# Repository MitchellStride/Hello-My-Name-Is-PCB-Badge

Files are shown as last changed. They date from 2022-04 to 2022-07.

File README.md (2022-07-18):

# The 'Hello my name is' PCB Badge
This **#Badgelife** PCB was created to test some circuits to be used in future art PCBs.
I also wanted a small project to bring to local hardware meetups. Partial assembly done at jlc.

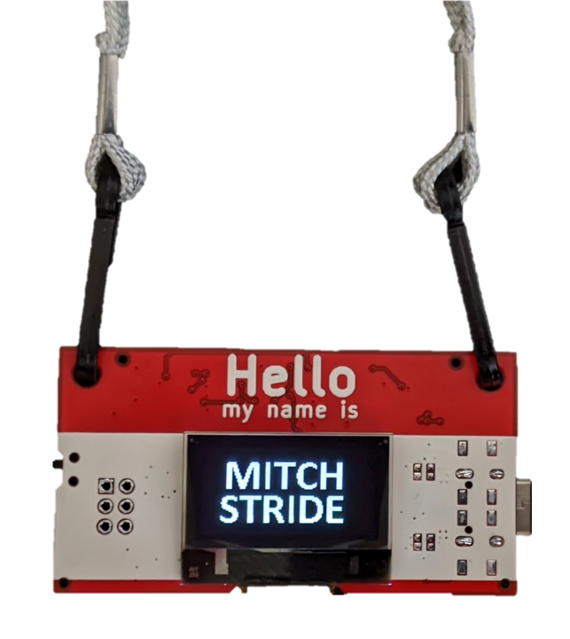
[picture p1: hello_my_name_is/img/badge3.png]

<br/>*missing front buttons on this test PCB
## Features:
* Powered by x2 AA Batteries
* Highly compatible with JLCPCB's basic SMT parts
* Raspberry Pi RP2040 uC w/ Dual core ARM Cortex-M0+
* OLED Screen, RGB LEDs, Buttons
* SAO Connector!

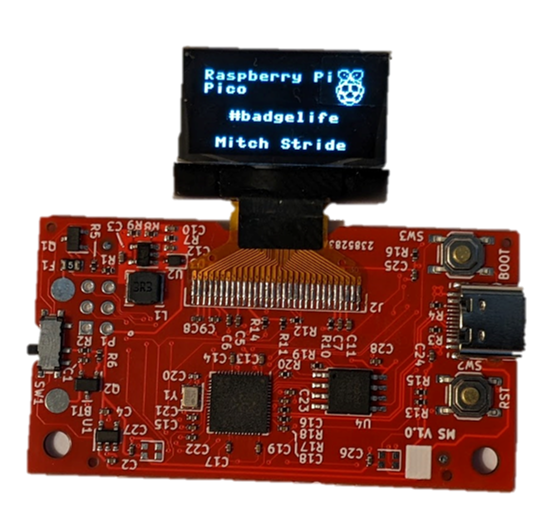
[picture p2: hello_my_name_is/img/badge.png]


## v1 Issues:
I rushed this project a lot. Schematic was done in a few nights, layout and routing in a few hours with no review. This PCB has a few mistakes. Not planning on making another board spin but leaving this list here. 
* I seen someone's design online using a RGB led running at 3.3V (below spec). I tried to replicate it and the LEDs were very flaky and worked intermittently. Experiment failed 😢.
* AA boost converter not yet tested, just using USB power so far.
### Possible v2 Wishlist [v2 Todo]:
* User led + pwr led 
* ON OFF silk on switch
* Buzzer would be fun
* 5.1k USB cc1 cc2
* Planes on batt terminals to prevent lifting
* Use RPI boost for AA supply instead of boost converter
		○ Its nice to have 5V for leds
* Sao is to big for this little thing.
* GND probe clip stuffing option
* lvl shifter for RGBs

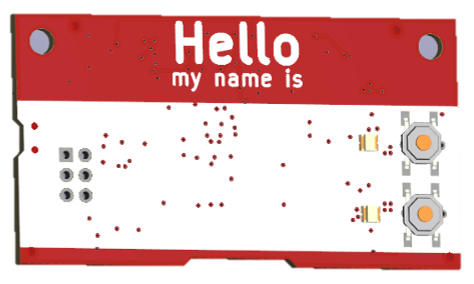
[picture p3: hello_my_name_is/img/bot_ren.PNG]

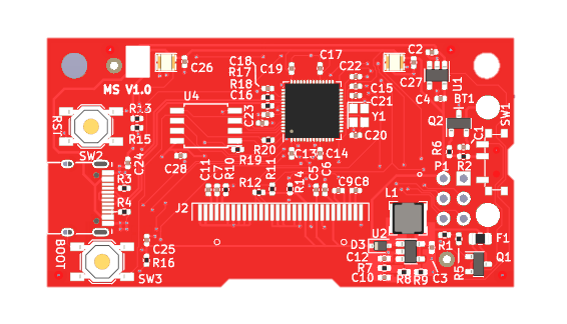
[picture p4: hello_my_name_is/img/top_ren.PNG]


## Example GIF ⚡


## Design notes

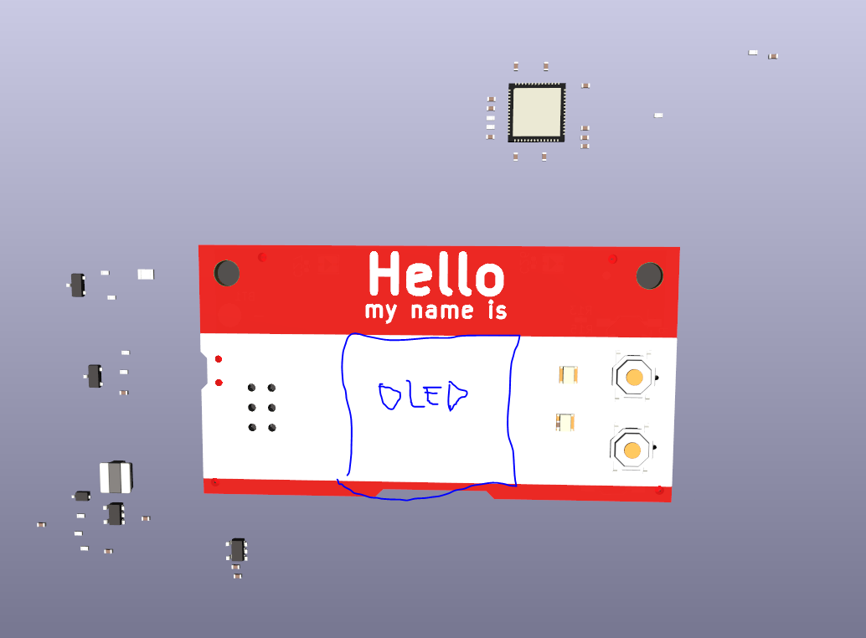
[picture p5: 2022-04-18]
hello_my_name_is/img/mockup.PNG

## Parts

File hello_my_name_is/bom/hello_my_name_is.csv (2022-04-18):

Reference | Quantity | Value | Footprint | Datasheet | digi | desc | lcsc | Field5
BT1 | 1 | AAx2 | ftp:BatteryHolder_MPD_BC2AAPC_2xAA_mod-SMD |  | BC2AAPC
C1 C5 C6 C8 C9 C12 C22 C23 C24 C25 C26 C27 C28 | 13 | 1u | Capacitor_SMD:C_0402_1005Metric |  |  | 25V X5R | C52923
C10 | 1 | 3.3p | Capacitor_SMD:C_0402_1005Metric |  |  |  | C1565
C13 C14 C15 C16 C17 C18 C19 | 7 | 0.1u | Capacitor_SMD:C_0402_1005Metric |  |  | 16V X7R | C1525
C2 C3 C4 C11 | 4 | 4.7u | Capacitor_SMD:C_0402_1005Metric |  |  | 10V X5R | C23733
C20 C21 | 2 | 12p | Capacitor_SMD:C_0402_1005Metric |  |  | 50V C0G | C1547
C7 | 1 | 2.2u | Capacitor_SMD:C_0402_1005Metric |  |  | 6.3V X5R | C12530
D1 D2 D4 D5 | 4 | WS2812B-2020 | ftp:WS2812B-2020 | https://www.tme.eu/Document/4a8239e52df5e0b5cc2eb96834c5d8b6/WS2812B-2020.pdf |  |  | C965555
D3 | 1 | 1N5819WS | Diode_SMD:D_SOD-323 |  |  | 40V 600mV@1A | C191023
F1 | 1 | 24V 500mA PTC | Fuse:Fuse_0805_2012Metric |  |  | NonAsm | C910822
J1 | 1 | USB_C_Receptacle_USB2.0 | ftp:USB-C-16p | https://www.usb.org/sites/default/files/documents/usb_type-c.zip |  |  | C167321
J2 | 1 | OLED | Display:OLED-128O064D |  |  | Shenzhen Allvision Tech N096-2864KSWEG01-H30 | C2890596
L1 | 1 | 3.3u | Inductor_SMD:L_Bourns-SRN4018 |  |  | ftp: Not Exact, 1.23A 3.3uH ±20% 70mΩ | C431259
P1 | 1 | SAO 2x3 IDC | ftp:Badgelife-SAOv169-BADGE-2x3 |  |  |  | C11214
Q1 | 1 | AO3401A | Package_TO_SOT_SMD:SOT-23 | http://www.aosmd.com/pdfs/datasheet/AO3401A.pdf |  |  | C15127
Q2 | 1 | AO3400A | Package_TO_SOT_SMD:SOT-23 | http://www.aosmd.com/pdfs/datasheet/AO3400A.pdf |  |  | C20917
R1 R2 R13 R14 R15 R16 R19 | 7 | 10k | Resistor_SMD:R_0402_1005Metric |  |  |  | C25744
R10 | 1 | 330k | Resistor_SMD:R_0402_1005Metric |  |  |  | C25778
R11 R12 | 2 | 4.7k | Resistor_SMD:R_0402_1005Metric |  |  |  | C25900
R17 R18 | 2 | 22 | Resistor_SMD:R_0402_1005Metric |  |  |  | C25092
R3 R4 | 2 | 56k | Resistor_SMD:R_0402_1005Metric |  |  |  | C25796
R5 R6 R20 | 3 | 1k | Resistor_SMD:R_0402_1005Metric |  |  |  | C11702
R7 | 1 | 200k | Resistor_SMD:R_0402_1005Metric |  |  |  | C25764
R8 | 1 | 51k | Resistor_SMD:R_0402_1005Metric |  |  |  | C25794
R9 | 1 | 150k | Resistor_SMD:R_0402_1005Metric |  |  |  | C25755
SW1 | 1 | SSSS811101 | ftp:SSSS811101 |  |  |  | C109335
SW2 SW3 SW4 SW5 | 4 | TS-1187A-B-A-B | Button_Switch_SMD:SW_SPST_TL3342 |  |  | ftp: Not Exact | C318884
U1 | 1 | RT9080-33GJ5 | Package_TO_SOT_SMD:SOT-23-5 | https://datasheet.lcsc.com/lcsc/2009192305_Richtek-Tech-RT9080-33GJ5_C841192.pdf |  | 3V3 600mA LDO | C841192
U2 | 1 | TPS61040DBV | Package_TO_SOT_SMD:SOT-23-5 | http://www.ti.com/lit/ds/symlink/tps61040.pdf |  |  | C7722
U3 | 1 | RP2040 | ftp:QFN-56_EP_7x7_Pitch0.4mm | https://datasheets.raspberrypi.org/rp2040/rp2040_datasheet.pdf |  |  | C2040
U4 | 1 | W25Q64JV | Package_SO:SOIC-8W_5.3x5.3mm_P1.27mm |  |  |  | C179171
Y1 | 1 | XYDBPCNANF-12MHZ | Crystal:Crystal_SMD_2520-4Pin_2.5x2.0mm |  |  |  | C521567

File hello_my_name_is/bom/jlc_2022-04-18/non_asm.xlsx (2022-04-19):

Reference | Value | Footprint | Quantity
BT1 | AAX2 | FTP:BATTERYHOLDER_MPD_BC2AAPC_2XAA_MOD-SMD | 1
J2 | OLED | DISPLAY:OLED-128O064D | 1
D1,D2,D4,D5 | WS2812B-2020 | FTP:WS2812B-2020 | 2
P1 | SAO 2X3 IDC | FTP:BADGELIFE-SAOV169-BADGE-2X3 | 0

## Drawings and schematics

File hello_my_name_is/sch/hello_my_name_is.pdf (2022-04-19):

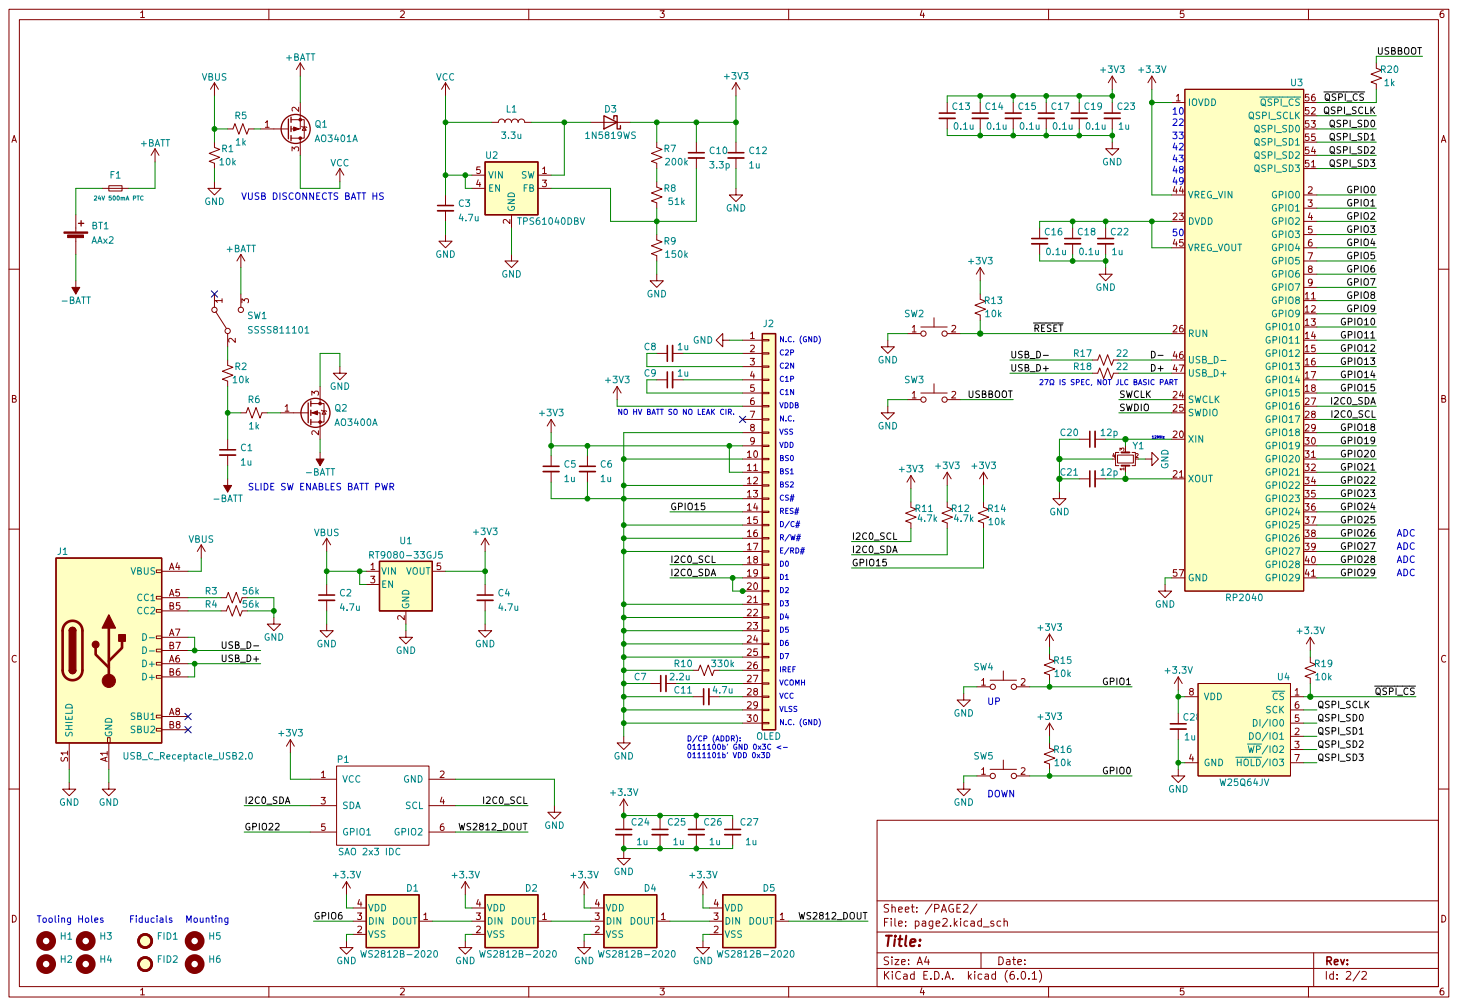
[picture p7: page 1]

þÿ27© IS SPEC, NOT JLC BASIC PART VUSB DISCONNECTS BATT HS

10
11

I2C0_SDA USB_D+ USB_D- SLIDE SW ENABLES BATT PWR
-BATT

D/CP (ADDR): 0111100b' GND 0x3C <- 0111101b' VDD 0x3D
1u GND GND

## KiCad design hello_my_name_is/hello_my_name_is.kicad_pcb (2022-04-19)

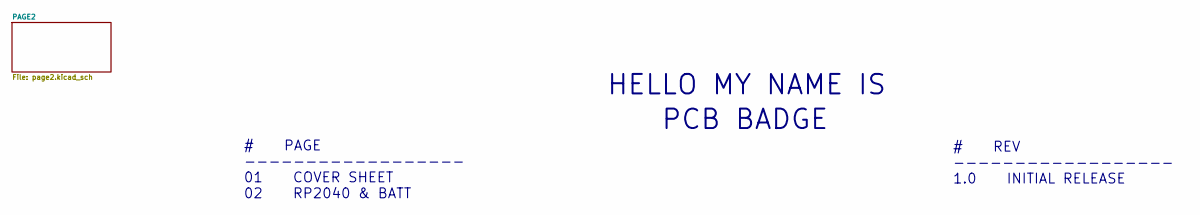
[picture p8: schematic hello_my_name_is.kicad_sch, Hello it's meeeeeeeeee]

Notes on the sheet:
# REV ------------------ 1.0 INITIAL RELEASE
HELLO MY NAME IS
PCB BADGE
# PAGE ------------------ 01 COVER SHEET 02 RP2040 & BATT

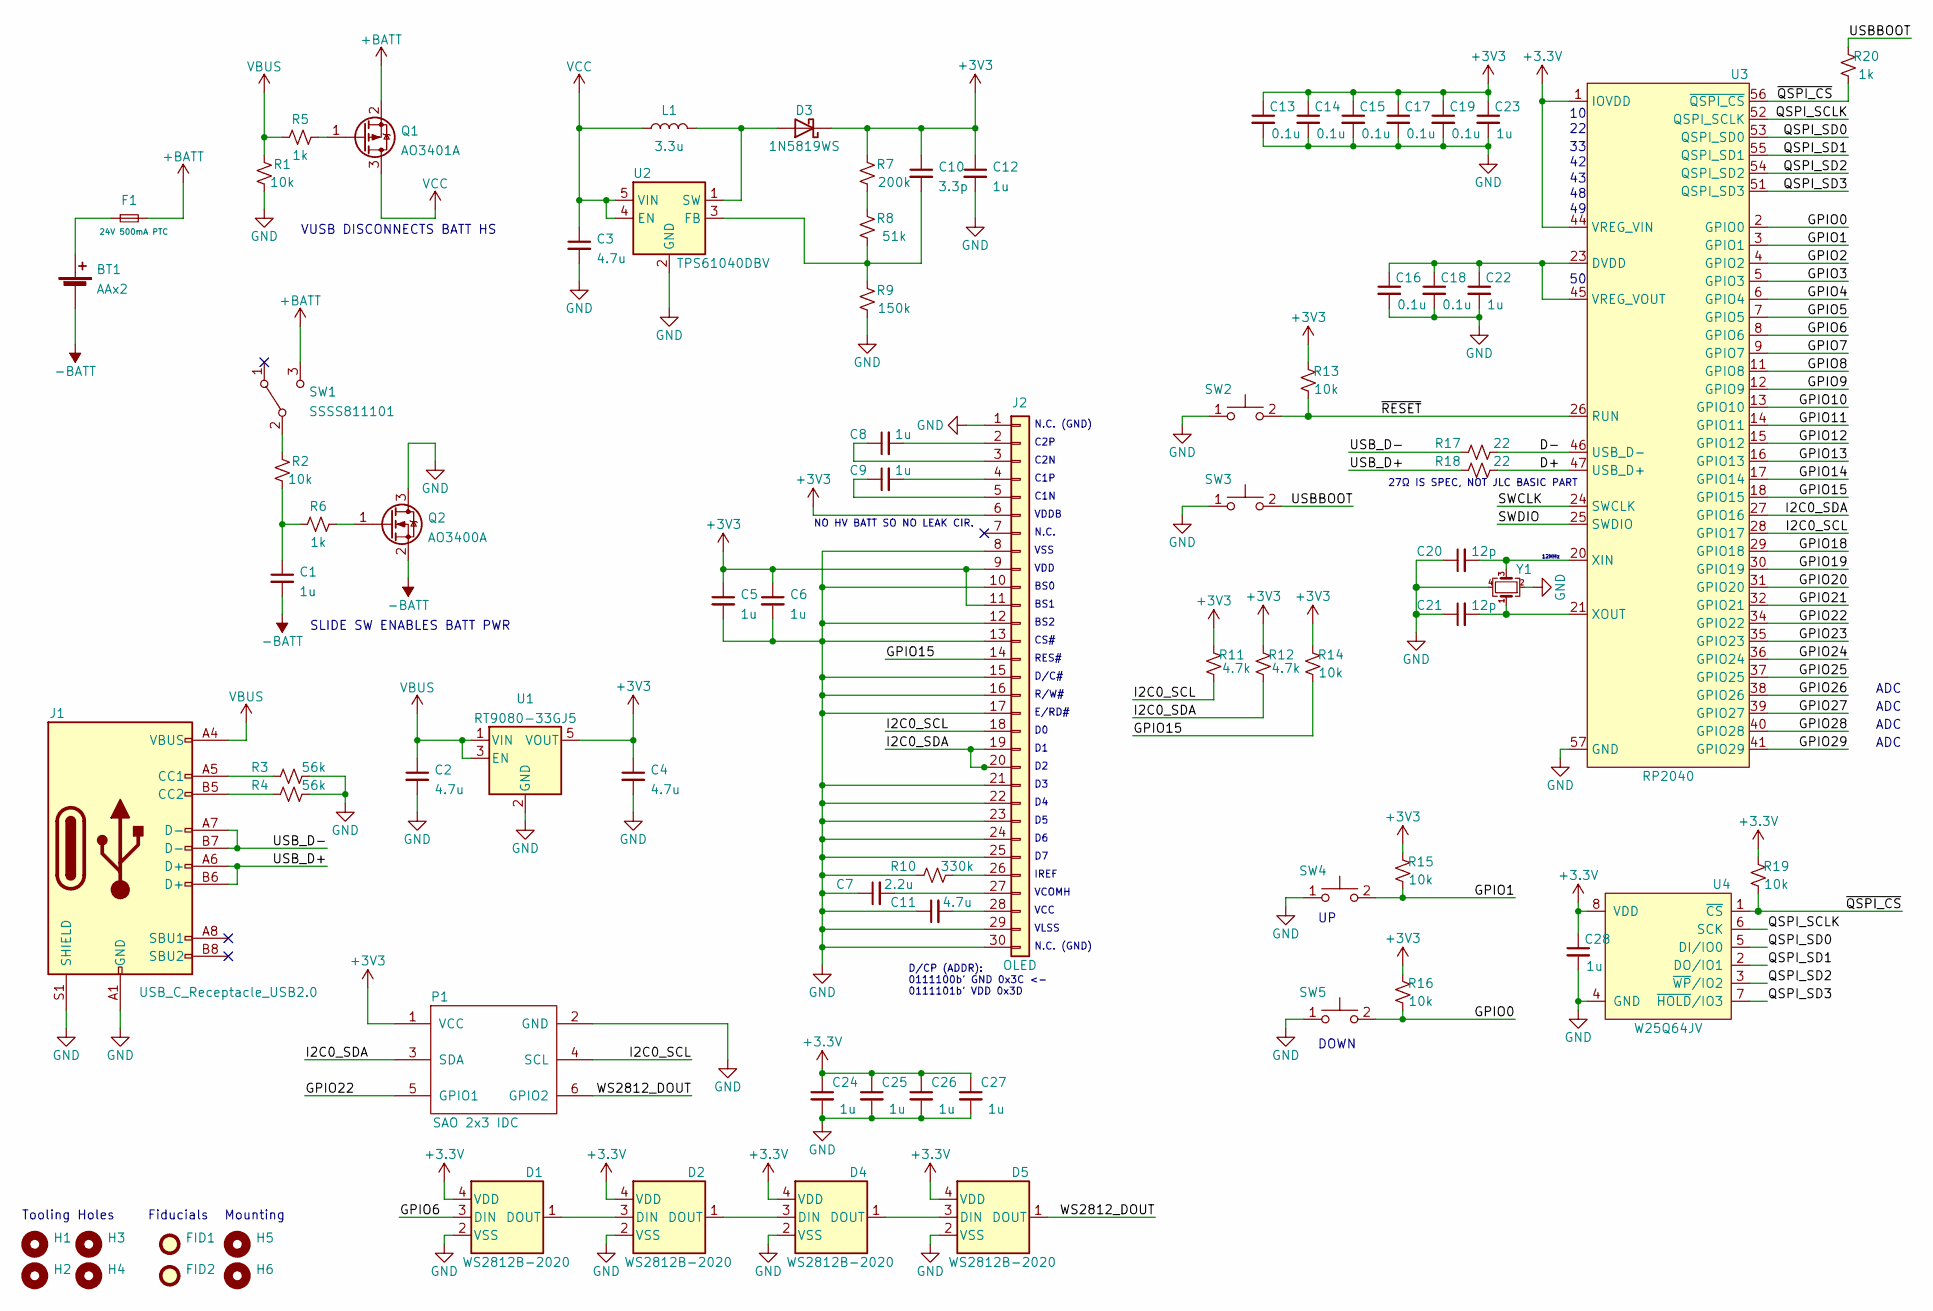
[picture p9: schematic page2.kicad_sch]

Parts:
BT1: AAx2; BatteryHolder_MPD_BC2AAPC_2xAA_mod-SMD; digi BC2AAPC
C1, C5, C6, C8, C9, C12, C22, C23, C24, C25, C26, C27, C28: 1u; C_0402_1005Metric; lcsc C52923
C2, C3, C4, C11: 4.7u; C_0402_1005Metric; lcsc C23733
C7: 2.2u; C_0402_1005Metric; lcsc C12530
C10: 3.3p; C_0402_1005Metric; lcsc C1565
C13, C14, C15, C16, C17, C18, C19: 0.1u; C_0402_1005Metric; lcsc C1525
C20, C21: 12p; C_0402_1005Metric; lcsc C1547
D1, D2, D4, D5: WS2812B-2020; lcsc C965555
D3: 1N5819WS; D_SOD-323; lcsc C191023
F1: 24V 500mA PTC; Fuse_0805_2012Metric; lcsc C910822
FID1, FID2: Fiducial; Fiducial_1mm_Mask2mm
H1, H2, H3, H4: Tooling_Hole_JLC; JLC_Tooling_Hole
H5, H6: Tooling_Hole_JLC; MountingHole_3.2mm_M3
J1: USB_C_Receptacle_USB2.0; USB-C-16p; lcsc C167321
J2: OLED; OLED-128O064D; lcsc C2890596
L1: 3.3u; L_Bourns-SRN4018; lcsc C431259
P1: SAO 2x3 IDC; Badgelife-SAOv169-BADGE-2x3; lcsc C11214
Q1: AO3401A; SOT-23; lcsc C15127
Q2: AO3400A; SOT-23; lcsc C20917
R1, R2, R13, R14, R15, R16, R19: 10k; R_0402_1005Metric; lcsc C25744
R3, R4: 56k; R_0402_1005Metric; lcsc C25796
R5, R6, R20: 1k; R_0402_1005Metric; lcsc C11702
R7: 200k; R_0402_1005Metric; lcsc C25764
R8: 51k; R_0402_1005Metric; lcsc C25794
R9: 150k; R_0402_1005Metric; lcsc C25755
R10: 330k; R_0402_1005Metric; lcsc C25778
R11, R12: 4.7k; R_0402_1005Metric; lcsc C25900
R17, R18: 22; R_0402_1005Metric; lcsc C25092
SW1: SSSS811101; lcsc C109335
SW2, SW3, SW4, SW5: TS-1187A-B-A-B; SW_SPST_TL3342; lcsc C318884
U1: RT9080-33GJ5; SOT-23-5; lcsc C841192
U2: TPS61040DBV; SOT-23-5; lcsc C7722
U3: RP2040; QFN-56_EP_7x7_Pitch0.4mm; lcsc C2040
U4: W25Q64JV; SOIC-8W_5.3x5.3mm_P1.27mm; lcsc C179171
Y1: XYDBPCNANF-12MHZ; Crystal_SMD_2520-4Pin_2.5x2.0mm; lcsc C521567

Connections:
+BATT: F1.2, Q1.2 (S), SW1.3 (C)
-BATT: BT1.2 (-), C1.2, Q2.2 (S)
/PAGE2/D+: R18.2, U3.47 (USB_D+)
/PAGE2/D-: R17.2, U3.46 (USB_D-)
/PAGE2/GPIO0: R16.2, SW5.2, U3.2 (GPIO0)
/PAGE2/GPIO1: R15.2, SW4.2, U3.3 (GPIO1)
/PAGE2/GPIO2: U3.4 (GPIO2)
/PAGE2/GPIO3: U3.5 (GPIO3)
/PAGE2/GPIO4: U3.6 (GPIO4)
/PAGE2/GPIO5: U3.7 (GPIO5)
/PAGE2/GPIO6: D1.3 (DIN), U3.8 (GPIO6)
/PAGE2/GPIO7: U3.9 (GPIO7)
/PAGE2/GPIO8: U3.11 (GPIO8)
/PAGE2/GPIO9: U3.12 (GPIO9)
/PAGE2/GPIO10: U3.13 (GPIO10)
/PAGE2/GPIO11: U3.14 (GPIO11)
/PAGE2/GPIO12: U3.15 (GPIO12)
/PAGE2/GPIO13: U3.16 (GPIO13)
/PAGE2/GPIO14: U3.17 (GPIO14)
/PAGE2/GPIO15: J2.14, R14.2, U3.18 (GPIO15)
/PAGE2/GPIO18: U3.29 (GPIO18)
/PAGE2/GPIO19: U3.30 (GPIO19)
/PAGE2/GPIO20: U3.31 (GPIO20)
/PAGE2/GPIO21: U3.32 (GPIO21)
/PAGE2/GPIO22: P1.5 (GPIO1), U3.34 (GPIO22)
/PAGE2/GPIO23: U3.35 (GPIO23)
/PAGE2/GPIO24: U3.36 (GPIO24)
/PAGE2/GPIO25: U3.37 (GPIO25)
/PAGE2/GPIO26: U3.38 (GPIO26)
/PAGE2/GPIO27: U3.39 (GPIO27)
/PAGE2/GPIO28: U3.40 (GPIO28)
/PAGE2/GPIO29: U3.41 (GPIO29)
/PAGE2/I2C0_SCL: J2.18, P1.4 (SCL), R11.2, U3.28 (GPIO17)
/PAGE2/I2C0_SDA: J2.19, J2.20, P1.3 (SDA), R12.2, U3.27 (GPIO16)
/PAGE2/QSPI_SCLK: U3.52 (QSPI_SCLK), U4.6 (SCK)
/PAGE2/QSPI_SD0: U3.53 (QSPI_SD0), U4.5 (DI/IO0)
/PAGE2/QSPI_SD1: U3.55 (QSPI_SD1), U4.2 (DO/IO1)
/PAGE2/QSPI_SD2: U3.54 (QSPI_SD2), U4.3 (~WP/IO2)
/PAGE2/QSPI_SD3: U3.51 (QSPI_SD3), U4.7 (~HOLD/IO3)
/PAGE2/SWCLK: U3.24 (SWCLK)
/PAGE2/SWDIO: U3.25 (SWDIO)
/PAGE2/USBBOOT: R20.1, SW3.2
/PAGE2/USB_D+: J1.A6 (D+), J1.B6 (D+), R18.1
/PAGE2/USB_D-: J1.A7 (D-), J1.B7 (D-), R17.1
/PAGE2/WS2812_DOUT: D5.1 (DOUT), P1.6 (GPIO2)
/PAGE2/~QSPI_CS: R19.2, R20.2, U3.56 (~QSPI_CS), U4.1 (~CS)
/PAGE2/~RESET: R13.2, SW2.2, U3.26 (RUN)
GND: C2.2, C3.2, C4.2, C5.2, C6.2, C7.1, C11.1, C12.2, C13.2, C14.2, C15.2, C16.2, C17.2, C18.2, C19.2, C20.1, C21.1, C22.2, C23.2, C24.2, C25.2, C26.2, C27.2, C28.2, D1.2 (VSS), D2.2 (VSS), D4.2 (VSS), D5.2 (VSS), J1.A1 (GND), J1.A12 (GND), J1.B1 (GND), J1.B12 (GND), J1.S1 (SHIELD), J2.1, J2.8, J2.10, J2.12, J2.13, J2.15, J2.16, J2.17, J2.21, J2.22, J2.23, J2.24, J2.25, J2.29, J2.30, P1.2 (GND), Q2.3 (D), R1.2, R3.2, R4.2, R9.2, R10.1, SW2.1, SW3.1, SW4.1, SW5.1, U1.2 (GND), U2.2 (GND), U3.19 (TESTEN), U3.57 (GND), U4.4 (GND), U4.9 (GND), Y1.2, Y1.4
unnamed: BT1.1 (+), F1.1
unnamed: C1.1, R2.2, R6.1
unnamed: C7.2, J2.27
unnamed: C8.1, J2.3
unnamed: C8.2, J2.2
unnamed: C9.1, J2.5
unnamed: C9.2, J2.4
unnamed: C10.2, R8.2, R9.1, U2.3 (FB)
unnamed: C11.2, J2.28
unnamed: C16.1, C18.1, C22.1, U3.23 (DVDD), U3.45 (VREG_VOUT), U3.50 (DVDD)
unnamed: C20.2, U3.20 (XIN), Y1.3
unnamed: C21.2, U3.21 (XOUT), Y1.1
unnamed: D1.1 (DOUT), D2.3 (DIN)
unnamed: D2.1 (DOUT), D4.3 (DIN)
unnamed: D3.2 (A), L1.2, U2.1 (SW)
unnamed: D4.1 (DOUT), D5.3 (DIN)
unnamed: J1.A5 (CC1), R3.1
unnamed: J1.B5 (CC2), R4.1
unnamed: J2.26, R10.2
unnamed: Q1.1 (G), R5.2
unnamed: Q2.1 (G), R6.2
unnamed: R2.1, SW1.2 (B)
unnamed: R7.2, R8.1
VBUS: C2.1, J1.A4 (VBUS), J1.A9 (VBUS), J1.B4 (VBUS), J1.B9 (VBUS), R1.1, R5.1, U1.1 (VIN), U1.3 (EN)
VCC: C3.1, L1.1, Q1.3 (D), U2.4 (EN), U2.5 (VIN)

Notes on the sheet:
C2N
C1P
D/C#
N.C. (GND)
RES#
Mounting
DOWN
CS#
IREF
VUSB DISCONNECTS BATT HS
BS2
NO HV BATT SO NO LEAK CIR.
D/CP (ADDR): 0111100b' GND 0x3C <- 0111101b' VDD 0x3D
R/W#
ADC
BS1
E/RD#
VCC
VDDB
VDD
27Ω IS SPEC, NOT JLC BASIC PART
Tooling Holes
SLIDE SW ENABLES BATT PWR
VSS
C1N
12MHz
VLSS
Fiducials
N.C.
BS0
VCOMH
C2P

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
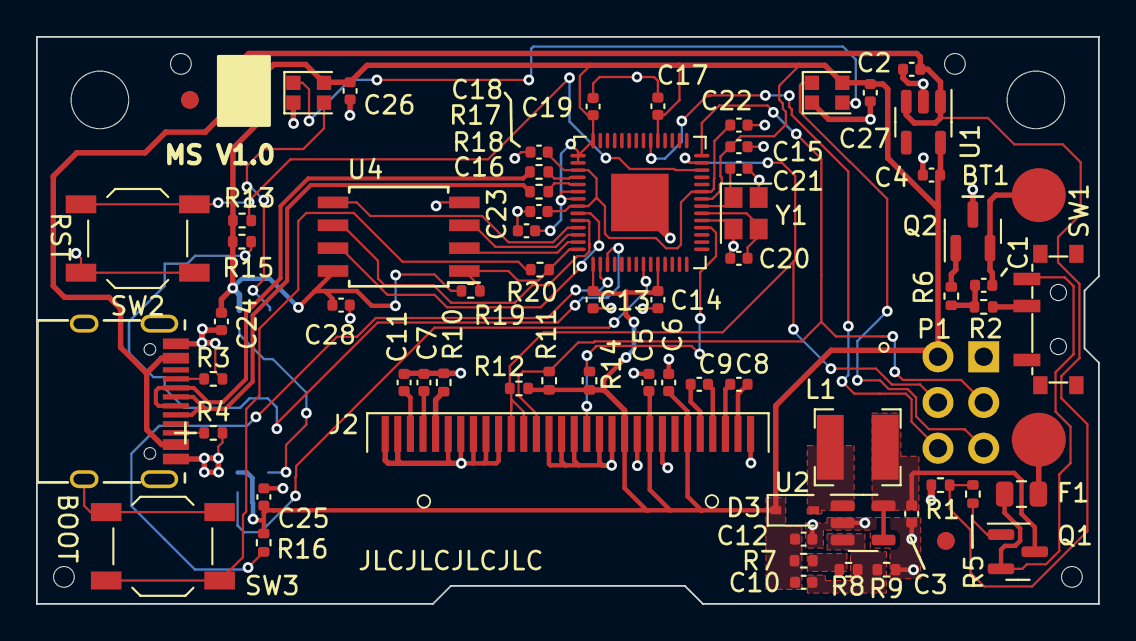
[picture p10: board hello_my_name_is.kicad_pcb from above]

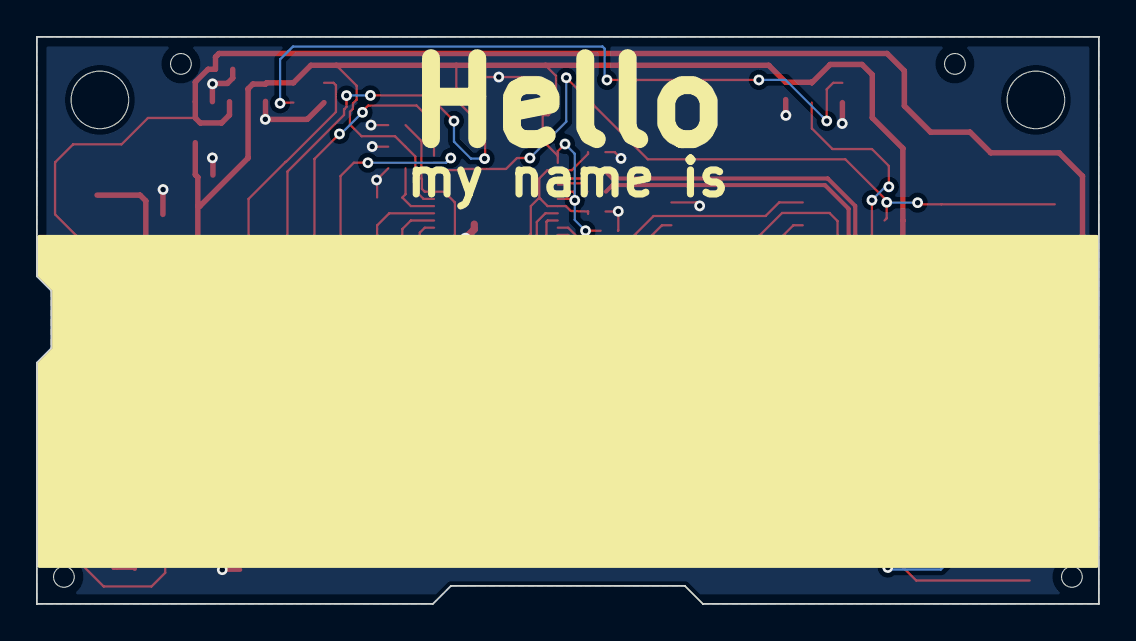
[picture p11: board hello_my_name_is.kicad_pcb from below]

Board: 2 copper layers, 59.0 x 31.5 mm, 79 parts (5 on the bottom side), 49 nets.

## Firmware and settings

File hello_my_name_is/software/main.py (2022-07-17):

"""***********************************************************
PROGRAM NAME:   main.py
PROGRAMMER:     M. STRIDE, 2022-07-17
DESCRIPTION:    Firmware for 'hello my name is' PCB badge.
TODO:           
BUGS:           
***********************************************************"""

'''
Program Description:
- Show Name > Buttons cycle to info page
- Info Page > Hometown [NL Pixel Map?], University, Job, Hobbies
'''

import machine
import utime
import ssd1306 #save ssd1306 lib to pico first
import framebuf

#PINS
button_SW4_UP = machine.Pin(1, machine.Pin.IN)
button_SW5_DOWN = machine.Pin(0, machine.Pin.IN) 
sensor_RP2040_die_temp = machine.ADC(4)
oled_rst = machine.Pin(15, machine.Pin.OUT)

#SETUP
oled_rst.low()
utime.sleep(0.1)
oled_rst.high()
utime.sleep(0.1)

#I2C
i2c0 = machine.I2C(0, sda=machine.Pin(16), scl=machine.Pin(17), freq=400000)

oled = ssd1306.SSD1306_I2C(width=128, height=64, i2c=i2c0, addr=0x3C)

#GLOBAL VARS
adc_conversion_factor = 3.3 / (65535)
button_c = 0
prev_button_press = 0
state = 0
state_flag = 1
#https://diyusthad.com/image2cpp
name_ms = bytearray(b'\x00\x00\x00\x00\x00\x00\x00\x00\x00\x00\x00\x00\x00\x00\x00\x00\x00\x00\x00\x00\x00\x00\x00\x00\x00\x00\x00\x00\x00\x00\x00\x00\x00\x00\x00\x00\x00\x00\x00\x00\x00\x00\x00\x00\x00\x00\x00\x00\x00\x00\x00\x00\x00\x00\x00\x00\x00\x00\x00\x00\x00\x00\x00\x00\x00\x00\x00\x00\x00\x00\x00\x00\x00\x00\x00\x00\x00\x00\x00\x00\x00\x00\x00\x00\x00\x00\x00\x00\x00\x00\x00\x00\x00\x00\x00\x00\x00\x00\x00\x00\x00\x00\x00\x00\x00\x00\x00\x00\x00\x00\x00\x00\x00\x00\x00\x00\x00\x00\x00\x00\x00\x00\x00\x00\x00\x00\x00\x00\x00\x00\x00\x00\x00\x00\x00\x00\x00\x00\x00\x00\x00\x00\x00\x00\x00\x00\x00\x00\x00\x00\x00\x00\x00\x00\x00\x00\x00\x00\x00\x00\x00\x00\x1f\x80\x0f\x81\xc7\xff\xf8\x07\xc0\xf0\x0f\x00\x00\x00\x00\x00\x3f\x80\x1f\xc1\xc7\xff\xf8\x3f\xf0\xf0\x0f\x00\x00\x00\x00\x00\x3f\xc0\x1f\xc1\xc7\xff\xf8\x7f\xf8\xf0\x0f\x00\x00\x00\x00\x00\x3f\xc0\x3f\xc1\xc0\x1e\x00\xfc\x38\xf0\x0f\x00\x00\x00\x00\x00\x3d\xc0\x3b\xc1\xc0\x1e\x00\xf0\x08\xf0\x0f\x00\x00\x00\x00\x00\x3d\xe0\x7b\xc1\xc0\x1e\x01\xe0\x00\xf0\x0f\x00\x00\x00\x00\x00\x3d\xe0\x73\xc1\xc0\x1e\x01\xe0\x00\xf0\x0f\x00\x00\x00\x00\x00\x3c\xe0\x73\xc1\xc0\x1e\x01\xe0\x00\xf0\x0f\x00\x00\x00\x00\x00\x3c\xf0\xf3\xc1\xc0\x1e\x03\xe0\x00\xff\xff\x00\x00\x00\x00\x00\x3c\xf0\xe3\xc1\xc0\x1e\x03\xe0\x00\xff\xff\x00\x00\x00\x00\x00\x3c\x78\xe3\xc1\xc0\x1e\x03\xe0\x00\xff\xff\x00\x00\x00\x00\x00\x3c\x79\xe3\xc1\xc0\x1e\x03\xe0\x00\xf0\x0f\x00\x00\x00\x00\x00\x3c\x39\xc3\xc1\xc0\x1e\x01\xe0\x00\xf0\x0f\x00\x00\x00\x00\x00\x3c\x3f\xc3\xc1\xc0\x1e\x01\xe0\x00\xf0\x0f\x00\x00\x00\x00\x00\x3c\x3f\xc3\xc1\xc0\x1e\x01\xe0\x00\xf0\x0f\x00\x00\x00\x00\x00\x3c\x1f\x83\xc1\xc0\x1e\x01\xf0\x08\xf0\x0f\x00\x00\x00\x00\x00\x3c\x1f\x83\xc1\xc0\x1e\x00\xf8\x38\xf0\x0f\x00\x00\x00\x00\x00\x3c\x1f\x83\xc1\xc0\x1e\x00\x7f\xf8\xf0\x0f\x00\x00\x00\x00\x00\x3c\x0f\x03\xc1\xc0\x1e\x00\x3f\xf0\xf0\x0f\x00\x00\x00\x00\x00\x3c\x0f\x03\xc1\xc0\x1e\x00\x0f\xc0\xf0\x0f\x00\x00\x00\x00\x00\x00\x00\x00\x00\x00\x00\x00\x00\x00\x00\x00\x00\x00\x00\x00\x00\x00\x00\x00\x00\x00\x00\x00\x00\x00\x00\x00\x00\x00\x00\x00\x00\x00\x00\x00\x00\x00\x00\x00\x00\x00\x00\x00\x00\x00\x00\x00\x00\x00\x00\x00\x00\x00\x00\x00\x00\x00\x00\x00\x00\x00\x00\x00\x00\x00\x00\x00\x00\x00\x00\x00\x00\x00\x00\x00\x00\x00\x00\x00\x00\x3f\x0f\xff\xf3\xff\x00\x70\x7f\xe0\x03\xff\x80\x00\x00\x00\x00\xff\xcf\xff\xf3\xff\xc0\x70\x7f\xfc\x07\xff\x80\x00\x00\x00\x01\xff\xcf\xff\xf3\xff\xe0\x70\x7f\xfe\x07\xff\x80\x00\x00\x00\x01\xe0\xc0\x3c\x03\xc1\xf0\x70\x78\x3f\x07\x80\x00\x00\x00\x00\x01\xe0\x00\x3c\x03\xc0\xf0\x70\x78\x0f\x87\x80\x00\x00\x00\x00\x03\xc0\x00\x3c\x03\xc0\xf0\x70\x78\x07\x87\x80\x00\x00\x00\x00\x01\xe0\x00\x3c\x03\xc0\xf0\x70\x78\x07\x87\x80\x00\x00\x00\x00\x01\xf8\x00\x3c\x03\xc0\xf0\x70\x78\x03\xc7\x80\x00\x00\x00\x00\x01\xfe\x00\x3c\x03\xc1\xe0\x70\x78\x03\xc7\xff\x00\x00\x00\x00\x00\xff\x80\x3c\x03\xff\xe0\x70\x78\x03\xc7\xff\x00\x00\x00\x00\x00\x3f\xc0\x3c\x03\xff\x80\x70\x78\x03\xc7\xff\x00\x00\x00\x00\x00\x0f\xc0\x3c\x03\xff\x80\x70\x78\x03\xc7\x80\x00\x00\x00\x00\x00\x03\xe0\x3c\x03\xc7\xc0\x70\x78\x03\xc7\x80\x00\x00\x00\x00\x00\x01\xe0\x3c\x03\xc3\xe0\x70\x78\x07\x87\x80\x00\x00\x00\x00\x00\x01\xe0\x3c\x03\xc1\xe0\x70\x78\x07\x87\x80\x00\x00\x00\x00\x02\x01\xe0\x3c\x03\xc1\xf0\x70\x78\x0f\x87\x80\x00\x00\x00\x00\x03\x83\xc0\x3c\x03\xc0\xf0\x70\x78\x3f\x07\x80\x00\x00\x00\x00\x03\xff\xc0\x3c\x03\xc0\xf0\x70\x7f\xfe\x07\xff\x80\x00\x00\x00\x01\xff\x80\x3c\x03\xc0\x78\x70\x7f\xfc\x07\xff\x80\x00\x00\x00\x00\x7e\x00\x3c\x03\xc0\x78\x70\x7f\xe0\x03\xff\x80\x00\x00\x00\x00\x00\x00\x00\x00\x00\x00\x00\x00\x00\x00\x00\x00\x00\x00\x00\x00\x00\x00\x00\x00\x00\x00\x00\x00\x00\x00\x00\x00\x00\x00\x00\x00\x00\x00\x00\x00\x00\x00\x00\x00\x00\x00\x00\x00\x00\x00\x00\x00\x00\x00\x00\x00\x00\x00\x00\x00\x00\x00\x00\x00\x00\x00\x00\x00\x00\x00\x00\x00\x00\x00\x00\x00\x00\x00\x00\x00\x00\x00\x00\x00\x00\x00\x00\x00\x00\x00\x00\x00\x00\x00\x00\x00\x00\x00\x00\x00\x00\x00\x00\x00\x00\x00\x00\x00\x00\x00\x00\x00\x00\x00\x00\x00\x00\x00\x00\x00\x00\x00\x00\x00\x00\x00\x00\x00\x00\x00\x00\x00\x00\x00\x00\x00\x00\x00\x00\x00\x00\x00\x00\x00\x00\x00')
nl_map = bytearray(b'\x00\x00\x00\x00\x00\x00\x00\x00\x00\x00\x00\x00\x00\x00\x00\x00\x00\x00\x00\x3e\x00\x00\x00\x00\x00\x00\x01\xe2\x00\x00\x00\x00\x00\x00\x01\x5e\x00\x00\x00\x00\x00\x00\x07\x30\x00\x00\x00\x00\x00\x00\x06\x30\x00\x00\x00\x00\x00\x00\x05\x78\x00\x00\x00\x00\x00\x00\x0c\x08\x00\x00\x00\x00\x00\x00\x19\x18\x00\x00\x00\x00\x00\x00\x19\x50\x00\x00\x00\x00\x00\x00\x08\x10\x00\x00\x00\x00\x00\x00\x19\x70\x00\x00\x00\x00\x00\x00\x20\x40\x00\x00\x00\x00\x00\x00\x20\x40\x00\x00\x00\x00\x00\x00\xe0\x40\x00\x00\x00\x00\x00\x00\x80\x40\x00\x00\x00\x00\x00\x00\xa9\xc0\x00\x00\x00\x00\x00\x00\x81\x00\x00\x00\x00\x00\x00\x00\x81\x00\x00\x00\x00\x00\x00\x01\xa9\x00\x00\x00\x00\x00\x00\x01\x81\x3f\x00\x00\x00\x00\x00\x01\x2b\x29\x80\x00\x00\x00\x00\x01\x2a\x29\x80\x00\x00\x00\x00\x01\x02\x21\x00\x00\x00\x00\x00\x01\x2a\xea\x00\x00\x00\x00\x00\x01\x03\x02\x00\x06\x00\x00\x00\x01\x00\x02\x00\x46\x00\x00\x00\x07\x29\x6b\xf0\x7f\xe0\x00\x00\x04\x00\x00\x0f\xc0\x20\x00\x00\x05\x29\x69\x5b\x4a\x60\x00\x00\x1d\x00\x08\x00\x40\x60\x00\x00\x18\x00\x00\x00\x00\xc0\x00\x00\x1f\x69\x6b\x4b\x4a\x80\x00\x00\x06\x00\x00\x00\x00\x80\x00\x00\x07\x29\x09\x48\x42\x80\x00\x00\x3f\x29\x49\x4a\x4a\x67\x80\x00\x30\x00\x00\x00\x00\x1f\x80\x00\x2d\x29\x6b\x4b\x5a\x5e\x00\x00\x20\x00\x00\x00\x00\x04\x00\x00\x20\x00\x00\x00\x00\x04\x00\x07\xed\x29\x69\x4b\x4a\x5c\x00\x1c\x00\x00\x00\x00\x00\x05\x80\x1f\xff\x29\x69\x4b\x4a\x7d\x80\x00\x30\x00\x00\x00\x00\x11\x80\x00\x30\x00\x00\x00\x00\x11\x80\x00\xed\x69\x6b\x4b\x4a\x52\x80\x01\x00\x00\x00\x00\x00\x12\x8c\x03\x21\x29\x09\x48\x4f\xf2\x8c\x05\x29\x29\x49\x4a\xce\x3e\xb4\x08\x00\x00\x00\x01\x66\x22\xa4\x1d\x2d\x69\x6f\xee\x7e\x3a\xd4\x10\x00\x00\x10\x28\x42\x20\x04\x18\x0f\xff\xf0\x38\x4e\x20\x1c\x05\x30\x00\x00\x01\xd0\x3a\x50\x07\xe0\x00\x00\x01\x70\x23\x10\x00\x00\x00\x00\x01\x40\x2d\x50\x00\x00\x00\x00\x07\x40\x31\x10\x00\x00\x00\x00\x04\xc0\x31\x10\x00\x00\x00\x00\x3b\x80\x31\xf0\x00\x00\x00\x00\x23\x00\x11\x80\x00\x00\x00\x00\x3c\x00\x01\x80\x00\x00\x00\x00\x00\x00\x00\x00\x00\x00\x00\x00\x00\x00\x00\x00')
nl_flag = bytearray(b'\x00\x00\x00\x00\x00\x00\x00\x00\x00\x00\x00\x00\x00\x00\x00\x00\x00\x00\x00\x00\x00\x00\x00\x00\x00\x00\x00\x00\x00\x00\x00\x00\x00\x00\x00\x00\x00\x00\x00\x00\x00\x00\x00\x00\x00\x00\x00\x00\x00\x03\xff\xff\xff\xff\xe0\x1f\xff\xff\xff\xff\xff\xff\xff\xf0\x00\x00\xff\xff\xff\xff\xe0\x1f\xff\xff\xff\xff\xff\xff\xff\x80\x00\x00\x3f\xff\xff\xff\xe0\x1f\xff\xff\xff\xff\xff\xff\xfc\x00\x00\x00\x0f\xff\xff\xff\xe0\x18\x00\x00\x00\x00\x00\x0f\xe0\x00\x0c\x00\x07\xff\xff\xff\xe0\x18\x00\x00\x00\x00\x00\x7f\x00\x00\x0f\x00\x01\xff\xff\xff\xe0\x18\x00\x00\x00\x00\x07\xf8\x00\x00\x0f\xc0\x00\x7f\xff\xff\xe0\x18\x00\x00\x00\x00\x3f\xc0\x00\x00\x0f\xf0\x00\x1f\xff\xff\xe0\x18\x00\x00\x00\x01\xfe\x00\x00\x00\x0f\xf8\x00\x07\xff\xff\xe0\x18\x00\x00\x00\x0f\xf0\x00\x00\x00\x0f\xfe\x00\x03\xff\xff\xe0\x18\x00\x00\x00\x7f\x80\x00\x00\x00\x0f\xff\x80\x00\xff\xff\xe0\x18\x00\x00\x03\xfc\x00\x00\x00\x00\x0f\xff\xe0\x00\x3f\xff\xe0\x18\x00\x00\x1f\xe0\x00\x00\x00\x00\x0f\xff\xf8\x00\x0f\xff\xe0\x18\x00\x00\xff\x00\x00\x00\x00\x00\x0f\xff\xfe\x00\x03\xff\xe0\x18\x00\x07\xf8\x00\x00\x00\x00\x00\x0f\xff\xff\x80\x00\xff\xe0\x18\x00\x3f\xc0\x00\x00\x00\x00\x00\x0f\xff\xff\xc0\x00\x7f\xe0\x18\x03\xfe\x00\x00\x00\x00\x00\x00\x0f\xff\xff\xf0\x00\x1f\xe0\x18\x1f\xf0\x00\x00\x00\x00\x00\x00\x0f\xff\xff\xfc\x00\x07\xe0\x18\xff\x80\x00\x00\x00\x00\x00\x00\x0f\xff\xff\xff\x00\x01\xe0\x1f\xfc\x00\x00\x00\x00\x00\x00\x00\x0f\xff\xff\xff\xc0\x00\x60\x1f\xe0\x00\x00\x00\x00\x00\x00\x00\x0f\xff\xff\xff\xe0\x00\x20\x1f\x00\x00\x00\x00\x00\x00\x00\x00\x0f\xff\xff\xff\xf8\x00\x00\x18\x00\x00\x00\x00\x00\x00\x00\x00\x0f\xff\xff\xff\xfe\x00\x00\x00\x00\x00\x00\x00\x00\x00\x00\x00\x0f\xff\xff\xff\xff\x80\x00\x00\x00\x00\x00\x00\x00\x00\x00\x00\x0f\xff\xff\xff\xff\xe0\x00\x00\x00\x00\x00\x00\x00\x00\x00\x00\x00\x00\x00\x00\x00\x00\x00\x0f\xff\xff\xff\xff\xff\xff\xff\xc0\x00\x00\x00\x00\x00\x00\x00\x06\x00\x00\x00\x00\x00\x00\x00\x60\x00\x00\x00\x00\x00\x00\x00\x03\x00\x00\x00\x00\x00\x00\x00\x30\x00\x00\x00\x00\x00\x00\x00\x01\x80\x00\x00\x00\x00\x00\x00\x18\x00\x00\x00\x00\x00\x00\x00\x03\x00\x00\x00\x00\x00\x00\x00\x30\x00\x00\x00\x00\x00\x00\x00\x06\x00\x00\x00\x00\x00\x00\x00\x60\x00\x00\x00\x00\x00\x00\x00\x0f\xff\xff\xff\xff\xff\xff\xff\xc0\x00\x00\x00\x00\x00\x00\x00\x00\x00\x00\x00\x00\x00\x00\x00\x00\x0f\xff\xff\xff\xff\x80\x00\x00\x00\x00\x00\x00\x00\x00\x00\x00\x0f\xff\xff\xff\xff\x00\x00\x00\x00\x00\x00\x00\x00\x00\x00\x00\x0f\xff\xff\xff\xfc\x00\x00\x10\x00\x00\x00\x00\x00\x00\x00\x00\x0f\xff\xff\xff\xf0\x00\x00\x1e\x00\x00\x00\x00\x00\x00\x00\x00\x0f\xff\xff\xff\xc0\x00\x60\x1f\xc0\x00\x00\x00\x00\x00\x00\x00\x0f\xff\xff\xff\x00\x01\xe0\x1f\xf8\x00\x00\x00\x00\x00\x00\x00\x0f\xff\xff\xfc\x00\x07\xe0\x19\xff\x00\x00\x00\x00\x00\x00\x00\x0f\xff\xff\xf8\x00\x0f\xe0\x18\x1f\xe0\x00\x00\x00\x00\x00\x00\x0f\xff\xff\xe0\x00\x3f\xe0\x18\x03\xfc\x00\x00\x00\x00\x00\x00\x0f\xff\xff\x80\x00\xff\xe0\x18\x00\x7f\x80\x00\x00\x00\x00\x00\x0f\xff\xfe\x00\x03\xff\xe0\x18\x00\x0f\xf0\x00\x00\x00\x00\x00\x0f\xff\xf8\x00\x0f\xff\xe0\x18\x00\x01\xfe\x00\x00\x00\x00\x00\x0f\xff\xf0\x00\x1f\xff\xe0\x18\x00\x00\x3f\xc0\x00\x00\x00\x00\x0f\xff\xc0\x00\x7f\xff\xe0\x18\x00\x00\x07\xf8\x00\x00\x00\x00\x0f\xff\x00\x01\xff\xff\xe0\x18\x00\x00\x00\xff\x00\x00\x00\x00\x0f\xfc\x00\x07\xff\xff\xe0\x18\x00\x00\x00\x1f\xe0\x00\x00\x00\x0f\xf0\x00\x1f\xff\xff\xe0\x18\x00\x00\x00\x03\xfc\x00\x00\x00\x0f\xc0\x00\x7f\xff\xff\xe0\x18\x00\x00\x00\x00\x3f\x80\x00\x00\x0f\x00\x01\xff\xff\xff\xe0\x18\x00\x00\x00\x00\x07\xf0\x00\x00\x0e\x00\x03\xff\xff\xff\xe0\x18\x00\x00\x00\x00\x00\xfe\x00\x00\x08\x00\x0f\xff\xff\xff\xe0\x18\x00\x00\x00\x00\x00\x1f\xc0\x00\x00\x00\x3f\xff\xff\xff\xe0\x1f\xff\xff\xff\xff\xff\xff\xf8\x00\x00\x00\xff\xff\xff\xff\xe0\x1f\xff\xff\xff\xff\xff\xff\xff\x00\x00\x01\xff\xff\xff\xff\xe0\x1f\xff\xff\xff\xff\xff\xff\xff\xe0\x00\x00\x00\x00\x00\x00\x00\x00\x00\x00\x00\x00\x00\x00\x00\x00\x00\x00\x00\x00\x00\x00\x00\x00\x00\x00\x00\x00\x00\x00\x00\x00\x00\x00\x00\x00\x00\x00\x00\x00\x00\x00\x00\x00\x00\x00\x00\x00\x00\x00\x00\x00\x00\x00\x00\x00\x00\x00\x00\x00\x00\x00\x00\x00')

#FUNCTIONS
def button_UP_pressed(pin):   #ISR
    global state, state_flag, prev_button_press
    new_time = utime.ticks_ms()
    if (new_time - prev_button_press) > 400:    #debounce
        prev_button_press = new_time
        state = state + 1
        state_flag = 1

def button_DOWN_pressed(pin):   #ISR
    global state, state_flag, prev_button_press
    new_time = utime.ticks_ms()
    if (new_time - prev_button_press) > 400:    #debounce
        prev_button_press = new_time
        state = state - 1
        state_flag = 1

def read_temp():
    data = sensor_RP2040_die_temp.read_u16() * adc_conversion_factor
    # Typically, Vbe = 0.706V @ 27°C, with a slope of -1.721mV (0.001721) per degree. 
    RP2040_die_temp = 27 - (data - 0.706)/0.001721
    return RP2040_die_temp

def oled_pixel_check():
    oled.fill(1)
    oled.show()
    utime.sleep(0.8)
    oled.fill(0)
    oled.show()
    
def oled_setup():
    oled_pixel_check()
    for i in range(8):
        oled.fill(0)   #clears screen
        oled.text("Hello my name is", 0, 0)
        oled.text("PCB badge", 0, 10)
        oled.text("RP2040 Die Temp:", 0, 30)
        oled.text(f'{read_temp():.1f}', 0, 40)
        oled.show()
        utime.sleep(1)
    
def state_machina():
    global state, state_flag
    prev_time = 0
    while True:
        #setting state bounds
        if state < 0:
            state = 4
        if state > 5:
            state = 0
            
        #default to name screen after <X> time
        new_time = utime.ticks_ms()
        if (new_time - prev_time) > (1*60*1000):    #1min
            prev_time = new_time
            state = 0
            state_flag = 1
        
        #Screen SM------
        if state_flag == 1:
            prev_time = utime.ticks_ms()
            state_flag = 0
            print(f'State [{state}]')
            if state == 0:
                fb = framebuf.FrameBuffer(name_ms, 128, 64, framebuf.MONO_HLSB)
                oled.blit(fb, 0, 0)   
                oled.show()
            if state == 1:
                oled.fill(0)
                oled.text("Hometown:", 0, 15)
                oled.text("Lewisporte, NL", 0, 25)
                oled.text("Canada", 0, 35)
                oled.show()
            if state == 2:
                oled.fill(0)
                fb = framebuf.FrameBuffer(nl_map, 64, 64, framebuf.MONO_HLSB)
                oled.blit(fb, 32, 0)
                oled.show()
            if state == 3:
                oled.fill(0)
                fb = framebuf.FrameBuffer(nl_flag, 128, 64, framebuf.MONO_HLSB)
                oled.blit(fb, 0, 0)
                oled.show()
            if state == 4:
                oled.fill(0)
                oled.text("Memorial", 0, 0)
                oled.text("University", 0, 10)
                oled.text("of Newfoundland", 0, 20)
                oled.text("Electrical", 0, 40)
                oled.text("Engineering", 0, 50)
                oled.show()
            if state == 5:
                oled.fill(0)
                oled.text("Hobbies:", 0, 0)
                oled.text("- Hiking", 0, 10)
                oled.text("- Electronics", 0, 20)
                oled.text("- Basketball", 0, 30)
                oled.text("- Video Games", 0, 40)
                oled.text("- Wine Brewing", 0, 50)
                oled.show()

#---------------------------MAIN-----------------------------------
def main():
    utime.sleep(0.5)   #wait for serial terminal
    print("'Hello my name is' PCB badge SW")
    button_SW4_UP.irq(trigger=machine.Pin.IRQ_FALLING,  handler=button_UP_pressed)
    button_SW5_DOWN.irq(trigger=machine.Pin.IRQ_FALLING,  handler=button_DOWN_pressed)
    
    oled_setup()
    state_machina()
    print("END")

if __name__ == "__main__":
    main()
#------------------------------------------------------------------

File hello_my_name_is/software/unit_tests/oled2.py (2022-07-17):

# https://pypi.org/project/oled-text/

# Display Image & text on I2C driven ssd1306 OLED display
from machine import Pin, I2C
from ssd1306 import SSD1306_I2C
import utime
import framebuf

#N096-2864KSWEG01-H30
WIDTH = 128 # oled display width
HEIGHT = 64 # oled display height

oled_rst = machine.Pin(15, machine.Pin.OUT)
oled_rst.low()
utime.sleep(0.1)
oled_rst.high()
i2c = machine.I2C(0, sda=machine.Pin(16), scl=machine.Pin(17))

#i2c = I2C(0) # Init I2C using I2C0 defaults,
#SCL=Pin(GP9), SDA=Pin(GP8), freq=400000
print("I2C Address : "+hex(i2c.scan()[0]).upper()) # Display device address
print("I2C Configuration: "+str(i2c)) # Display I2C config

oled = SSD1306_I2C(WIDTH, HEIGHT, i2c) # Init oled display

# Raspberry Pi logo as 32x32 bytearray
buffer = bytearray(b"\x00\x00\x00\x00\x00\x00\x00\x00\x00\x00\x00\x00\x00|?\x00\x01\x86@\x80\x01\x01\x80\x80\x01\x11\x88\x80\x01\x05\xa0\x80\x00\x83\xc1\x00\x00C\xe3\x00\x00~\xfc\x00\x00L'\x00\x00\x9c\x11\x00\x00\xbf\xfd\x00\x00\xe1\x87\x00\x01\xc1\x83\x80\x02A\x82@\x02A\x82@\x02\xc1\xc2@\x02\xf6>\xc0\x01\xfc=\x80\x01\x18\x18\x80\x01\x88\x10\x80\x00\x8c!\x00\x00\x87\xf1\x00\x00\x7f\xf6\x00\x008\x1c\x00\x00\x0c \x00\x00\x03\xc0\x00\x00\x00\x00\x00\x00\x00\x00\x00\x00\x00\x00\x00")
buffer2 = bytearray(b'\xff\xff\xff\xff\xff\xff\xff\xff\xff\xff\xff\xff\xff\xff\xff\xff\xff\xff\xff\xff\xff\xff\xff\xff\xff\xff\xff\xff\xff\xff\xff\xff\xff\xff\xff\xff\xff\xff\xff\xff\xff\xff\xff\xff\xff\xff\xff\xff\xff\xff\xff\xff\xff\xff\xff\xff\xff\xff\xff\xff\xff\xff\xff\xff\xff\xff\xff\xff\xff\xff\xff\xff\xff\xff\xff\xff\xff\xff\xff\xff\xff\xff\xff\xff\xff\xff\xff\xff\xff\xff\xff\xff\xff\xff\xff\xff\xff\xff\xff\xff\xff\xff\xff\xff\xff\xff\xff\xff\xff\xff\xff\xff\xff\xff\xff\xff\xff\xff\xff\xff\xff\xff\xff\xff\xff\xff\xff\xff\xff\xff\xff\xff\xff\xff\xff\xff\xff\xff\xff\xff\xff\xff\xff\xff\xff\xff\xff\xff\xff\xff\xff\xff\xff\xff\xff\xff\xff\xff\xff\xff\xff\xff\xe0\x7f\xf0\x7e\x38\x00\x07\xf8\x3f\x0f\xf0\xff\xff\xff\xff\xff\xc0\x7f\xe0\x3e\x38\x00\x07\xc0\x0f\x0f\xf0\xff\xff\xff\xff\xff\xc0\x3f\xe0\x3e\x38\x00\x07\x80\x07\x0f\xf0\xff\xff\xff\xff\xff\xc0\x3f\xc0\x3e\x3f\xe1\xff\x03\xc7\x0f\xf0\xff\xff\xff\xff\xff\xc2\x3f\xc4\x3e\x3f\xe1\xff\x0f\xf7\x0f\xf0\xff\xff\xff\xff\xff\xc2\x1f\x84\x3e\x3f\xe1\xfe\x1f\xff\x0f\xf0\xff\xff\xff\xff\xff\xc2\x1f\x8c\x3e\x3f\xe1\xfe\x1f\xff\x0f\xf0\xff\xff\xff\xff\xff\xc3\x1f\x8c\x3e\x3f\xe1\xfe\x1f\xff\x0f\xf0\xff\xff\xff\xff\xff\xc3\x0f\x0c\x3e\x3f\xe1\xfc\x1f\xff\x00\x00\xff\xff\xff\xff\xff\xc3\x0f\x1c\x3e\x3f\xe1\xfc\x1f\xff\x00\x00\xff\xff\xff\xff\xff\xc3\x87\x1c\x3e\x3f\xe1\xfc\x1f\xff\x00\x00\xff\xff\xff\xff\xff\xc3\x86\x1c\x3e\x3f\xe1\xfc\x1f\xff\x0f\xf0\xff\xff\xff\xff\xff\xc3\xc6\x3c\x3e\x3f\xe1\xfe\x1f\xff\x0f\xf0\xff\xff\xff\xff\xff\xc3\xc0\x3c\x3e\x3f\xe1\xfe\x1f\xff\x0f\xf0\xff\xff\xff\xff\xff\xc3\xc0\x3c\x3e\x3f\xe1\xfe\x1f\xff\x0f\xf0\xff\xff\xff\xff\xff\xc3\xe0\x7c\x3e\x3f\xe1\xfe\x0f\xf7\x0f\xf0\xff\xff\xff\xff\xff\xc3\xe0\x7c\x3e\x3f\xe1\xff\x07\xc7\x0f\xf0\xff\xff\xff\xff\xff\xc3\xe0\x7c\x3e\x3f\xe1\xff\x80\x07\x0f\xf0\xff\xff\xff\xff\xff\xc3\xf0\xfc\x3e\x3f\xe1\xff\xc0\x0f\x0f\xf0\xff\xff\xff\xff\xff\xc3\xf0\xfc\x3e\x3f\xe1\xff\xf0\x3f\x0f\xf0\xff\xff\xff\xff\xff\xff\xff\xff\xff\xff\xff\xff\xff\xff\xff\xff\xff\xff\xff\xff\xff\xff\xff\xff\xff\xff\xff\xff\xff\xff\xff\xff\xff\xff\xff\xff\xff\xff\xff\xff\xff\xff\xff\xff\xff\xff\xff\xff\xff\xff\xff\xff\xff\xff\xff\xff\xff\xff\xff\xff\xff\xff\xff\xff\xff\xff\xff\xff\xff\xff\xff\xff\xff\xff\xff\xff\xff\xff\xff\xff\xff\xff\xff\xff\xff\xc0\xf0\x00\x0c\x00\xff\x8f\x80\x1f\xfc\x00\x7f\xff\xff\xff\xff\x00\x30\x00\x0c\x00\x3f\x8f\x80\x03\xf8\x00\x7f\xff\xff\xff\xfe\x00\x30\x00\x0c\x00\x1f\x8f\x80\x01\xf8\x00\x7f\xff\xff\xff\xfe\x1f\x3f\xc3\xfc\x3e\x0f\x8f\x87\xc0\xf8\x7f\xff\xff\xff\xff\xfe\x1f\xff\xc3\xfc\x3f\x0f\x8f\x87\xf0\x78\x7f\xff\xff\xff\xff\xfc\x3f\xff\xc3\xfc\x3f\x0f\x8f\x87\xf8\x78\x7f\xff\xff\xff\xff\xfe\x1f\xff\xc3\xfc\x3f\x0f\x8f\x87\xf8\x78\x7f\xff\xff\xff\xff\xfe\x07\xff\xc3\xfc\x3f\x0f\x8f\x87\xfc\x38\x7f\xff\xff\xff\xff\xfe\x01\xff\xc3\xfc\x3e\x1f\x8f\x87\xfc\x38\x00\xff\xff\xff\xff\xff\x00\x7f\xc3\xfc\x00\x1f\x8f\x87\xfc\x38\x00\xff\xff\xff\xff\xff\xc0\x3f\xc3\xfc\x00\x7f\x8f\x87\xfc\x38\x00\xff\xff\xff\xff\xff\xf0\x3f\xc3\xfc\x00\x7f\x8f\x87\xfc\x38\x7f\xff\xff\xff\xff\xff\xfc\x1f\xc3\xfc\x38\x3f\x8f\x87\xfc\x38\x7f\xff\xff\xff\xff\xff\xfe\x1f\xc3\xfc\x3c\x1f\x8f\x87\xf8\x78\x7f\xff\xff\xff\xff\xff\xfe\x1f\xc3\xfc\x3e\x1f\x8f\x87\xf8\x78\x7f\xff\xff\xff\xff\xfd\xfe\x1f\xc3\xfc\x3e\x0f\x8f\x87\xf0\x78\x7f\xff\xff\xff\xff\xfc\x7c\x3f\xc3\xfc\x3f\x0f\x8f\x87\xc0\xf8\x7f\xff\xff\xff\xff\xfc\x00\x3f\xc3\xfc\x3f\x0f\x8f\x80\x01\xf8\x00\x7f\xff\xff\xff\xfe\x00\x7f\xc3\xfc\x3f\x87\x8f\x80\x03\xf8\x00\x7f\xff\xff\xff\xff\x81\xff\xc3\xfc\x3f\x87\x8f\x80\x1f\xfc\x00\x7f\xff\xff\xff\xff\xff\xff\xff\xff\xff\xff\xff\xff\xff\xff\xff\xff\xff\xff\xff\xff\xff\xff\xff\xff\xff\xff\xff\xff\xff\xff\xff\xff\xff\xff\xff\xff\xff\xff\xff\xff\xff\xff\xff\xff\xff\xff\xff\xff\xff\xff\xff\xff\xff\xff\xff\xff\xff\xff\xff\xff\xff\xff\xff\xff\xff\xff\xff\xff\xff\xff\xff\xff\xff\xff\xff\xff\xff\xff\xff\xff\xff\xff\xff\xff\xff\xff\xff\xff\xff\xff\xff\xff\xff\xff\xff\xff\xff\xff\xff\xff\xff\xff\xff\xff\xff\xff\xff\xff\xff\xff\xff\xff\xff\xff\xff\xff\xff\xff\xff\xff\xff\xff\xff\xff\xff\xff\xff\xff\xff\xff\xff\xff\xff\xff\xff\xff\xff\xff\xff\xff\xff\xff\xff\xff\xff\xff')
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

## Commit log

2022-04-13 first create
    [hello_my_name_is.kicad_pcb, hello_my_name_is.kicad_sch]
2022-04-16 sch update
    [hello_my_name_is.kicad_pcb, hello_my_name_is.kicad_sch, page1.kicad_sch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]
2022-04-18 sch push before review, some component grouping
    [TPS61040.xlsx, hello_my_name_is.csv, hello_my_name_is.kicad_pcb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]
2022-04-19 uploading gerbers, going in hot w/ no review
    shotgunned this 2 layer board routing in a few hours... hot garbage!
    [asm.xls, hello_my_name_is.kicad_pcb, non_asm.xlsx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]
2022-04-29 drafted working badge test code for buttons
2022-05-11 sw transfer
    [page2.kicad_sch]
